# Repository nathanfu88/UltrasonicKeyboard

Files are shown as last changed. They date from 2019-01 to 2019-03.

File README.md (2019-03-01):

# Ultrasonic Keyboard

Ultrasonic Keyboard is an electronics project that uses an Arduino, an ultrasonic sensor, and a piezobuzzer to create a mock piano keyboard that plays tones using distance readings from the sensor. The idea takes inspiration from the [theremin](https://en.wikipedia.org/wiki/Theremin).

This project is not intended to be used functionally. Instead, it is meant to serve as a basic introduction to working with microcontrollers, circuitry, and digital audio.

## Materials
To assemble this project, you'll need:
- 1x Arduino Nano
- 1x HC-SR04 Ultrasonic Sensor
- 1x Piezo Buzzer
- 1x Pushbutton
- 1x 10kOhm Resistor

## Schematic
Here is a schematic of the circuit:
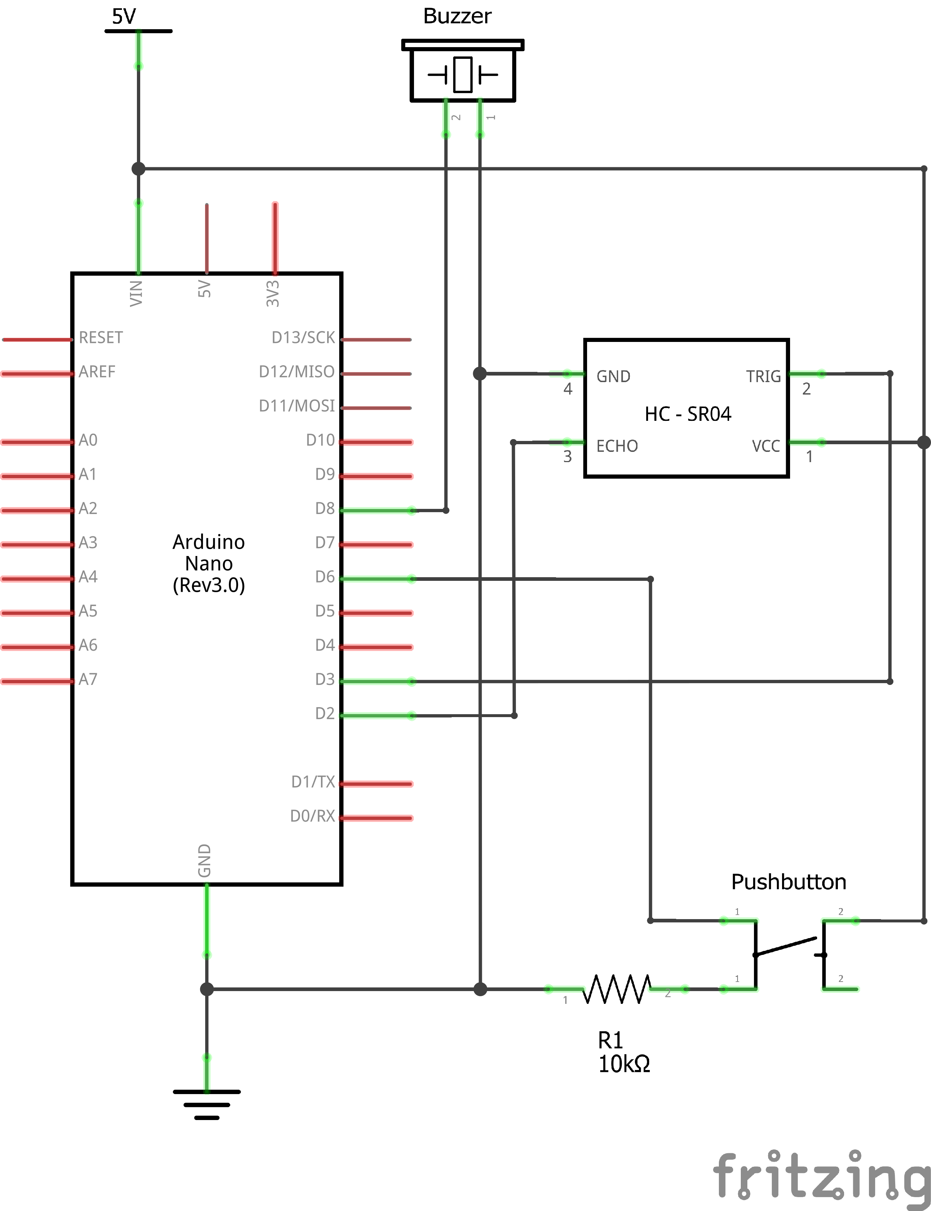
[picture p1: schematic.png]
Schematic


The pushbutton is used as a mute switch and the resistor is a pulldown with a 10 kOhm value as [suggested by Arduino's pins tutorial](https://www.arduino.cc/en/Tutorial/DigitalPins). The on-board LED will light up if the buzzer is muted.

## Assembly
There are a few pieces to put together for this project.

### Circuit
An example of how this circuit can be put together on a breadboard:
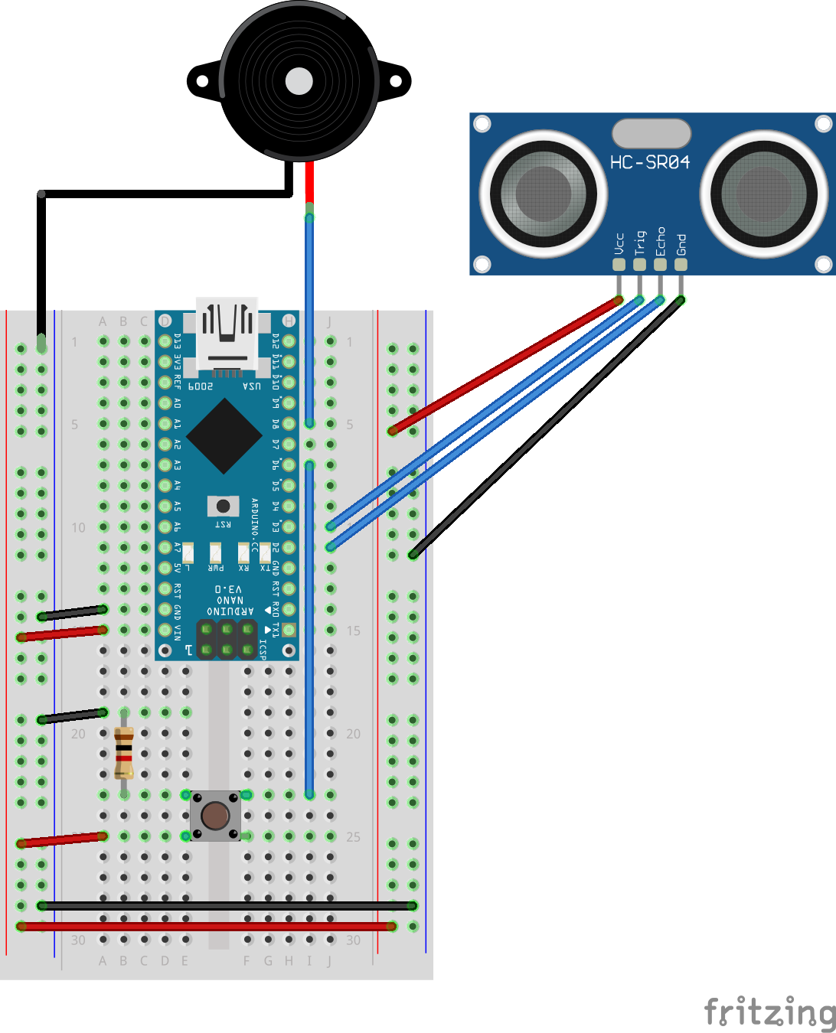
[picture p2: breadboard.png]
Breadboard


### Keyboard
Print out the [keyboard](keyboard_print.svg) on four pieces of standard letter paper (8.5" x 11") in landscape mode. Cut out the groupings of keys and tape them together to create the "full" [two-octave keyboard](keyboard.svg)

### Workspace
Some things to consider when setting up the work space:
- The entire keyboard is about 70 cm (~27.5 in) long
- There needs to be about 2 cm from the sensor to the start of the keyboard
	- The HC-SR04 has a minimum distance of 2 cm
- The circuit described above assumes the circuit is receiving power over USB
	- Space can be simplified if there is a separate power source

The best orientation is to have the assembled circuit on the left, with the HC-SR04 mounted in a case and facing right. The image belows shows such a configuration.

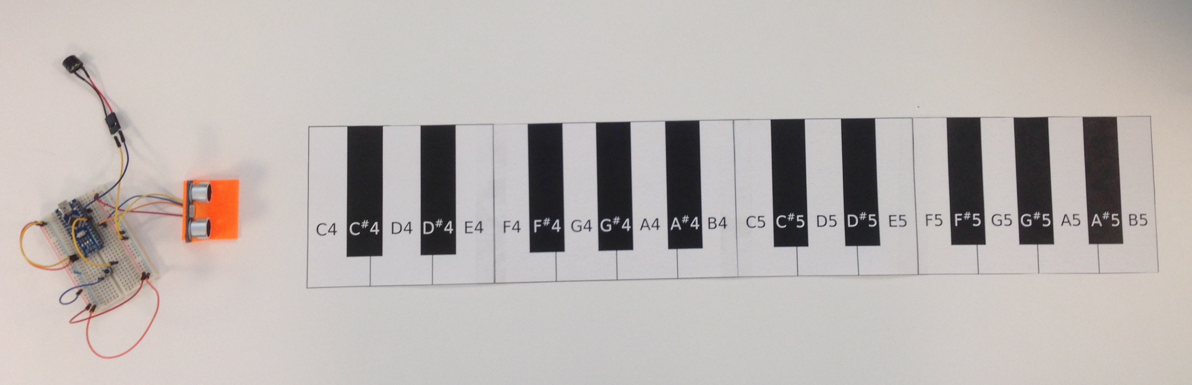
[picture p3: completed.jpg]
Completed keyboard


## Using the Keyboard
The entire configuration requires that the HC-SR04 direction be parallel to the surface that the keyboard rests on. This usually means that the HC-SR04 needs to be propped up, mounted, or in an enclosure. This project also includes a [mount model](hc-sr04_mount.stl) that can be 3D printed and will support the HC-SR04 so that it will suit a usable configuration.

The sensor needs to be at least 2 cm from the start of the keyboard so that the keyboard distances match what the microcontroller code is programmed for. The plastic extension of the 3D mount roughly matches the minimum distance, but you may still need to "calibrate" the position by finding the minimum distance at which the buzzer emits a noise and align your C4.

To play notes, move a solid object (the "reflector") over the desired key in front of the sensor to "obstruct it". A flat object works best, as any bends in the reflector can redirect the ultrasonic waves so that the reader is unable to detect them.

To play a melody, position your reflector over the proper notes, lifting the reflector up (in the Z-axis) to unobstruct the sensor so it plays no sound between notes.

## How It Works
The HC-SR04 module emits an ultrasonic sound wave and detects its reflection, effectively measuring the distance between the sensor and the reflected object. See the [HC-SR04 manual](https://docs.google.com/document/d/1Y-yZnNhMYy7rwhAgyL_pfa39RsB-x2qR4vP8saG73rE/edit#!) for more details about the module's operation.

The piano keyboard was designed such that the individual keys have an acceptable margin of error and still correlate with a particular note. This results in a mapping of distance ranges with musical notes. The mapping of distances to notes is done by estimation. Instead of having a table of notes mapped to distance ranges, the distance read from the sensor is divided by a specially chosen value (through trial and error) and the result is rounded to get the closest note.

The piezo buzzer can emit a sound wave at a designated frequency (you can see the note frequency definitions in [pitches.h](ultrasonickeyboard/pitches.h)), and so, will play a sound based on the distance the sensor reads.

The mute circuitry (pushbutton and resistor) is meant to silence the buzzer for assistance in quick debugging situations, or to stop the buzzer from going off without having to remove the buzzer or power source.

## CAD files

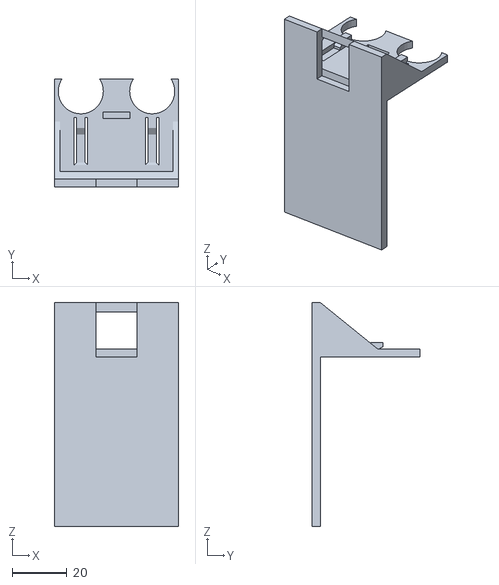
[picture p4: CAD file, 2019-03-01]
hc-sr04_mount.stl
45.5 x 39.5 x 82.0

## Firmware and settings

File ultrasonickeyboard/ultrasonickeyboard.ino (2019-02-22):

#include "pitches.h"

const byte ECHO_PIN = 2;     // HC-SR04 Echo pin (D2)
const byte TRIG_PIN = 3;     // HC-SR04 Trigger pin (D3)
const byte BUZZER_PIN = 8;   // Piezo speaker pin (D8)
const byte MUTE_PIN = 6;     // Push button mute pin (D6)

// Distance (in cm) the keyboard should start from the sensor
// HC-SR04's suggested minimum distance is 2 cm
const float DIST_OFFSET = 2.0;

// Estimated value to easily get note index from distance
const float AVG_NOTE_DIST = 2.75;
// Number of notes to limit playing sounds past a certain distance
const byte NUM_NOTES = 24;
const int NOTES[] = {
  0, NOTE_C4, NOTE_CS4, NOTE_D4, NOTE_DS4, NOTE_E4, NOTE_F4,
  NOTE_FS4, NOTE_G4, NOTE_GS4, NOTE_A4, NOTE_AS4, NOTE_B4,
  NOTE_C5, NOTE_CS5, NOTE_D5, NOTE_DS5, NOTE_E5, NOTE_F5,
  NOTE_FS5, NOTE_G5, NOTE_GS5, NOTE_A5, NOTE_AS5, NOTE_B5,
};

// Delay (in ms) before reading the sensor again
const int POLL_DELAY = 800;
// Required to use a push button as a toggle switch
byte prevButtonState = LOW;

bool muted = false;

void setup() {
  // Define HC-SR04 I/O
  pinMode(ECHO_PIN, INPUT);
  pinMode(TRIG_PIN, OUTPUT);

  // Define mute pushbutton input
  pinMode(MUTE_PIN, INPUT);

  // Initialize on-board LED for mute signaling
  pinMode(LED_BUILTIN, OUTPUT);
}

void loop() {
  // Check for input of mute pushbutton
  byte newButtonState = digitalRead(MUTE_PIN);
  if (newButtonState == HIGH && prevButtonState == LOW) {
    muted = !muted;
  }

  prevButtonState = newButtonState;

  // Only send ultrasonic pulses if we are not muted
  if (!muted) {
    digitalWrite(LED_BUILTIN, LOW);
    
    /**
     * Send a ultrasonic pulse
     * 
     * HC-SR04 uses a HIGH pulse for 10+ usec
     * Emit a LOW signal of 5 usec first to handle noise for a "clean" pulse
     */
    digitalWrite(TRIG_PIN, LOW);
    delayMicroseconds(5);
    digitalWrite(TRIG_PIN, HIGH);
    delayMicroseconds(10);
    // "Close" the pulse with a LOW
    digitalWrite(TRIG_PIN, LOW);
  
   /**
    * Read signal from sensor
    * 
    * Reading from the ECHO_PIN will be the time (in usec) of reflection
    * Keep in mind that the duration is "time in flight", so the distance
    * of the object from the sensor is actually `time in flight / 2`
    */
    pinMode(ECHO_PIN, INPUT);
    long duration = pulseIn(ECHO_PIN, HIGH) / 2;
   
    /**
     * Convert the time into distance
     * 
     * Speed of sound at room temp (~68F) is ~343 m/s
     * 343*10^-6 m/us => 343*10^-4 cm/us
     * To get distance (in cm) from time (in us): `duration` * 343 * 10^-4
     */
    float cm = (float)duration * 0.0343;
  
    /**
     * Play note
     * 
     * Frequencies stored in NOTES[]. Each key from the printout maps to
     * a note. Each note has a span of distance that varies. To make it
     * easier to determine the note, I use a rough estimation by dividing
     * the distance by the distance between notes on the printout.
     * 
     * The quotient is the number note to play from C4 (since C4 is the
     * first note in the printout).
     * 
     * If the distance is outside the printout's keyboard range, do not
     * play any sound
     */
    byte noteIndex = round((cm - DIST_OFFSET) / AVG_NOTE_DIST) - 1;
    if (noteIndex > NUM_NOTES) {
      noteIndex = 0;
    }
    
    if (noteIndex == 0) {
      noTone(BUZZER_PIN);
    }
    else {
      tone(BUZZER_PIN, NOTES[noteIndex]);
    }
  
    // Add some delay to prevent flooding
    delay(POLL_DELAY);
  }
  else {
    // We are muted, so do not send or attempt to read ultrasonic pulse
    digitalWrite(LED_BUILTIN, HIGH);
  }
}

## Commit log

2019-01-31 Changes schematic to png and updates README
2019-03-01 Adds completed image reference and 3D mount model
    [hc-sr04_mount.stl]
